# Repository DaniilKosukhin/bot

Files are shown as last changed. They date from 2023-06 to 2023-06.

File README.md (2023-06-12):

# bot

The bot passed three tests out of four in 2 minutes and 12 seconds

To meet the condition of the project were chosen not round wheels, but spiked in 4 rows of cones.

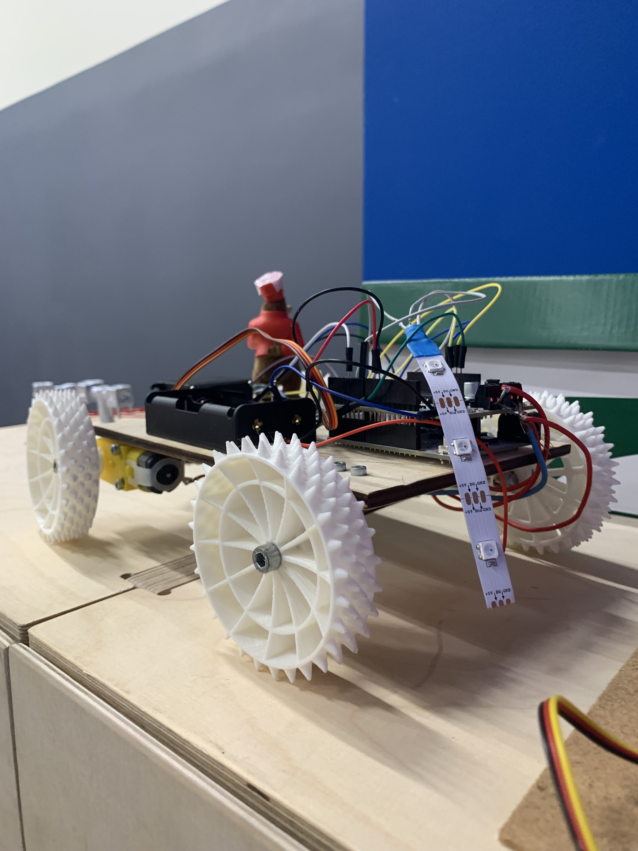
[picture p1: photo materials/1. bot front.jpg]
bot front


Bear holds radio module on his hat, for quality signal reception

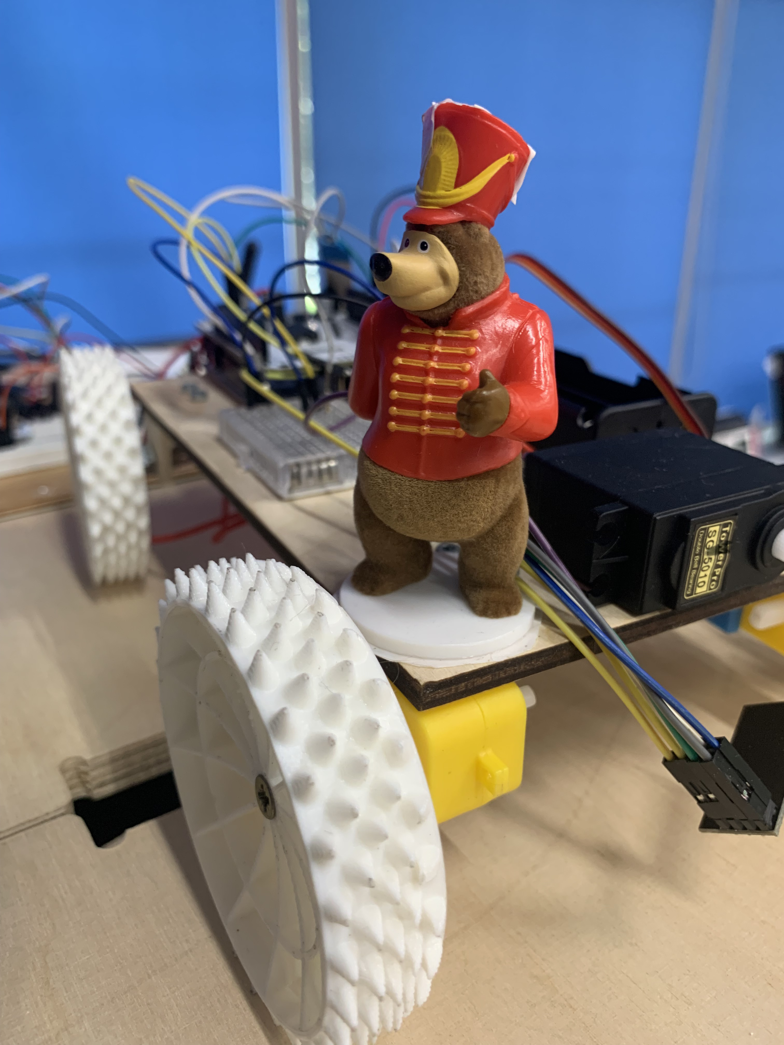
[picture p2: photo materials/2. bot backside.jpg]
bot backside


Joystick components assembled on a piece of cardboard

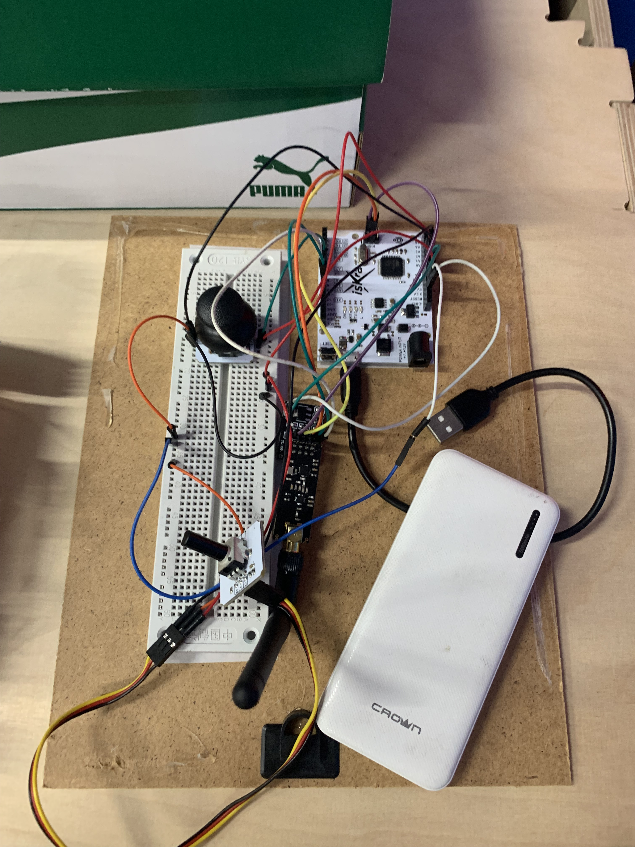
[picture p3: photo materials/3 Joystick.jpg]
joystick


Robot in motion :oncoming_automobile:

https://github.com/DaniilKosukhin/bot/assets/114745140/df838239-0182-4846-968c-9d25e73ed891

### componenets:
+ 3D jostick
+ amperka iskra NEO 2x
+ NRF
+ NRF +
+ 5v to 3.3 v
+ potentiometer
+ powerbank
+ servo 360
+ RGB LED matrix
+ battery holder
+ Motor Shield
+ DC motor 2x

### bot code:

```Python
#include <SPI.h>
#include <RF24.h>
#include <nRF24L01.h>
#include <Servo.h>
#include <Adafruit_NeoPixel.h>

#define SPEED_1      5 
#define DIR_1        4
 
#define SPEED_2      6
#define DIR_2        7

#define LED_COUNT 3
#define MATRIX_PIN 12

Adafruit_NeoPixel matrix = Adafruit_NeoPixel(LED_COUNT, MATRIX_PIN, NEO_GRB + NEO_KHZ800);

const uint64_t pipe = 0xF0F1F2F3F4LL;

RF24 radio(9, 10);

int data[5];

Servo rotServo; 
int servoAngle;

void setup(){
 Serial.begin(9600);
 radio.begin(); 
 radio.setChannel(3);
 radio.setDataRate(RF24_1MBPS);
 radio.setPALevel (RF24_PA_HIGH); 
 radio.openReadingPipe(1, pipe); 
 radio.startListening();
 
  for (int i = 4; i < 8; i++) {     
    pinMode(i, OUTPUT);
  } 

  rotServo.attach(2);
  matrix.begin();
} 

void loop() {

 if (radio.available()) {

    radio.read(&data, sizeof(data));

    int ptmrVal = data[0];
    int btnState = data[1];

    servoAngle = map(ptmrVal, 0, 1023, 0, 180); 
    rotServo.write(servoAngle); 
    Serial.println(ptmrVal);

      if (btnState == 0) {
        for (int i = 0; i < LED_COUNT; i++) {
          matrix.setPixelColor(i, matrix.Color(255,0,100));
        }
        matrix.show();
      }
      else {
        for (int i = 0; i < LED_COUNT; i++) {
          matrix.setPixelColor(i, matrix.Color(0,0,0));
        }
        matrix.show();
      }
      
    switch (data[2]) {
      case 0: {
        digitalWrite(DIR_1, HIGH); // set direction
        analogWrite(SPEED_1, data[3]); // set speed

        digitalWrite(DIR_2, HIGH); 
        analogWrite(SPEED_2, data[3]); 

        break;
      }
      case 1: {
            digitalWrite(DIR_1, LOW);
            analogWrite(SPEED_1, data[3]); 

            digitalWrite(DIR_2, LOW);
            analogWrite(SPEED_2, data[3]); 

            break;
          }
        case 2: {
          digitalWrite(DIR_1, LOW);
          analogWrite(SPEED_1, data[3]); 

          digitalWrite(DIR_2, HIGH);
          analogWrite(SPEED_2, data[3]); 

          break;
        }
        case 3: {
          digitalWrite(DIR_1, HIGH);
          analogWrite(SPEED_1, data[3]); 

          digitalWrite(DIR_2, LOW);
          analogWrite(SPEED_2, data[3]); 

          break;
        }
        case 4: {
          digitalWrite(DIR_1, LOW);
          analogWrite(SPEED_1, 0); 

          digitalWrite(DIR_2, LOW);
          analogWrite(SPEED_2, 0); 

          break;
        }
    }
  }
}
```

### jostick code:

```Python
#include <SPI.h>
#include <RF24.h>
#include <nRF24L01.h>

const uint64_t pipe = 0xF0F1F2F3F4LL;

RF24 radio(9, 10);

int data[5];

const int ptmrPin = A5;
const int buttonPin = 7;
const int xPin = A0;
const int yPin = A1;

int ptmrState = 0;
int buttonState = 0;
int xPosition = 0;
int yPosition = 0;

int speed = 0;
int direction = 0;

void setup(){
 Serial.begin(9600);

 radio.begin(); 
 radio.setChannel(3);
 radio.setDataRate(RF24_1MBPS);
 radio.setPALevel (RF24_PA_HIGH); 
 radio.openWritingPipe(pipe); 
 radio.stopListening(); 

 pinMode(ptmrPin, INPUT);
 pinMode(buttonPin, INPUT_PULLUP);
 pinMode(xPin, INPUT);
 pinMode(yPin, INPUT);
} 

void loop() {

 ptmrState = analogRead(ptmrPin);
 buttonState = digitalRead(buttonPin);
 xPosition = analogRead(xPin);
 yPosition = analogRead(yPin);

  if (yPosition < 400) {
        // go forward
        direction = 0; // 0 - Forward, 1 - backward, 2 - right, 3 - left
        speed = map(yPosition, 400, 10, 5, 255);
      }
      else if (yPosition > 600) {
        // go backward
        direction = 1;
        speed = map(yPosition, 600, 950, 5, 255);
      }
      else if (xPosition < 400) {
        // go right
        direction = 2; // 0 - Forward, 1 - backward, 2 - right, 3 - left
        speed = map(xPosition, 400, 0, 5, 255);
      }
      else if (xPosition > 600) {
      // go left
        direction = 3; // 0 - Forward, 1 - backward, 2 - right, 3 - left
        speed = map(xPosition, 600, 1000, 5, 255);
      }
      else if (yPosition < 600 || yPosition > 400  ) {
        // stop
        direction = 4;
        speed = 0;
      }

 data[0] = ptmrState;
 data[1] = !buttonState;
 data[2] = direction;
 data[3] = speed;

    radio.write(&data, sizeof(data));

    Serial.println(ptmrState); Serial.print(!buttonState);

    delay(100);
}
```

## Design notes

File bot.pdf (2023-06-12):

МИНИСТЕРСТВО НАУКИ И ВЫСШЕГО ОБРАЗОВАНИЯ РОССИЙСКОЙ

ФЕДЕРАЦИИ

ФЕДЕРАЛЬНОЕ ГОСУДАРСТВЕННОЕ АВТОНОМНОЕ

ОБРАЗОВАТЕЛЬНОЕ УЧРЕЖДЕНИЕ ВЫСШЕГО ОБРАЗОВАНИЯ

НАЦИОНАЛЬНЫЙ ИССЛЕДОВАТЕЛЬСКИЙ ТЕХНОЛОГИЧЕСКИЙ

УНИВЕРСИТЕТ «МИСиС»

ИНСТИТУТ Экотехнологий и инжиниринга

КАФЕДРА Металловедения цветных металлов

НАПРАВЛЕНИЕ 15.04.02 Технологические машины и оборудование

ПРАКТИКА ЦИФРОВОГО ПРОИВОДСТВА

на тему: «Робот на радиоуправлении»

Студент: Косухин Д.А.

Группа: МТМО-22-3

Преподаватель: Тавитов А.Г.

Москва, 2022

Введение

Целью практического занятия было создание робота на

радиоуправлении для прохождения полосы препятствий на время (Рис. 1).

Конструкция разрабатывалась исходя из сути испытаний и условия не

использовать колеса.

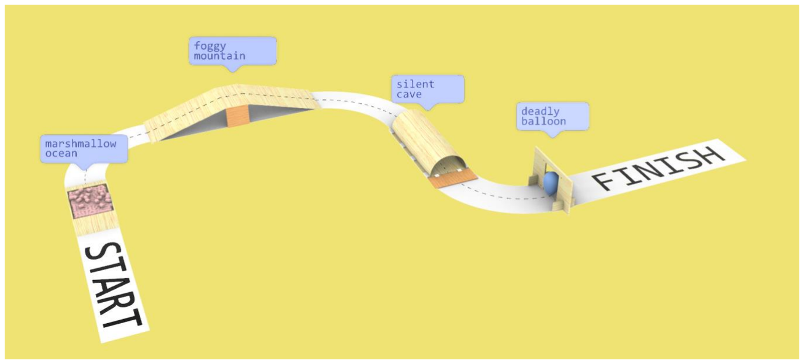
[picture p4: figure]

Рисунок 1 – Полоса препятствий. marshmallow ocean - бассейн с

зефиром глубиной 50 мм, foggy mountain - горка высотой 200 мм, шириной

320 мм и углом наклона 16 град., silent cave - тоннель длинной 1300 мм и

высотой 290 мм, ворота которого открываются при увеличениии

освещенности (срабатывает фоторезистор), deadly balloon - шарик,

привязанный к арке, отделяющий робота от финиша.

Компоненты

В проекте были использованы следующие компоненты:

1. 3D jostick
2. amperka iskra NEO 2x
3. NRF
4. NRF +
5. 5v to 3.3 v
6. potentiometer
7. powerbank
8. servo 360
9. RGB LED matrix
10. battery holder
11. Motor Shield
12. DC motor 2x

В последний день перед зачетом, техника отказывалась реагировать на

сигналы передатчика. Метод перебора каждого компонента, причина

поломки была найдена. Радиоприемный модуль, установленный на корпусе

машины, перестал принимать сигнал от передатчика на пульте.

В день экзамена радиомодуль удалось успешно заменить. Все

заработало.

Разработка изделия

В качестве основы корпуса робота был выбран лист МДФ, на лазерном

станке была получена заготовка толщиной 10 мм, шириной 200 мм и длиной

150 мм.

На сайте thingiverse.com была найдена модель колес, соответствующая

требованиям (рис. 2)

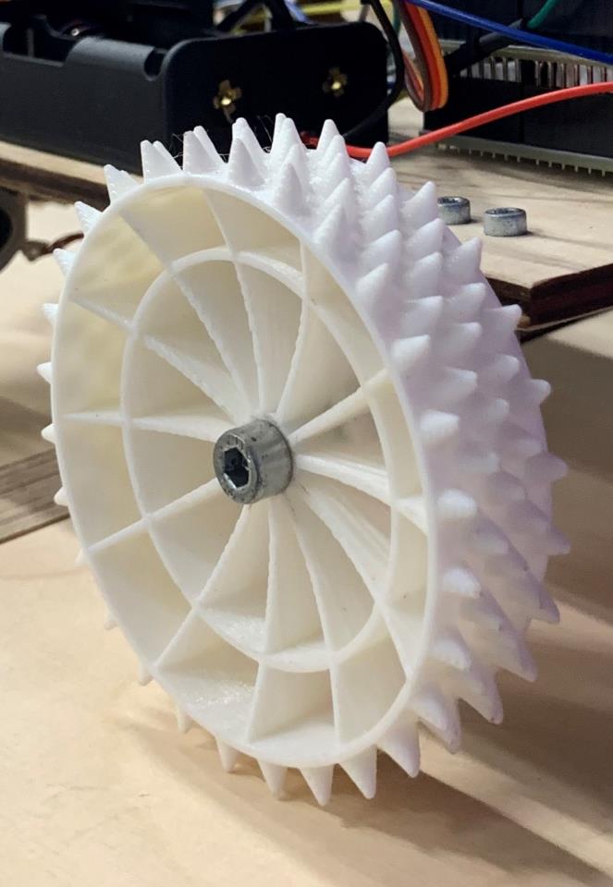
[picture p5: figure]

Рисунок 2 – Выбранная модель колес.

К МДФ были прикручены держатели моторов, предварительно

напечатанные на 3D принтере.

На следующем этапе возникла необходимость в разработке изделия,

способного соединить колеса и DC моторы. Деталь с одной стороны имеет многогранную выпуклую поверхность для сцепления с колесом, а с другой

отверстие для посадки с натягом с валом мотора.

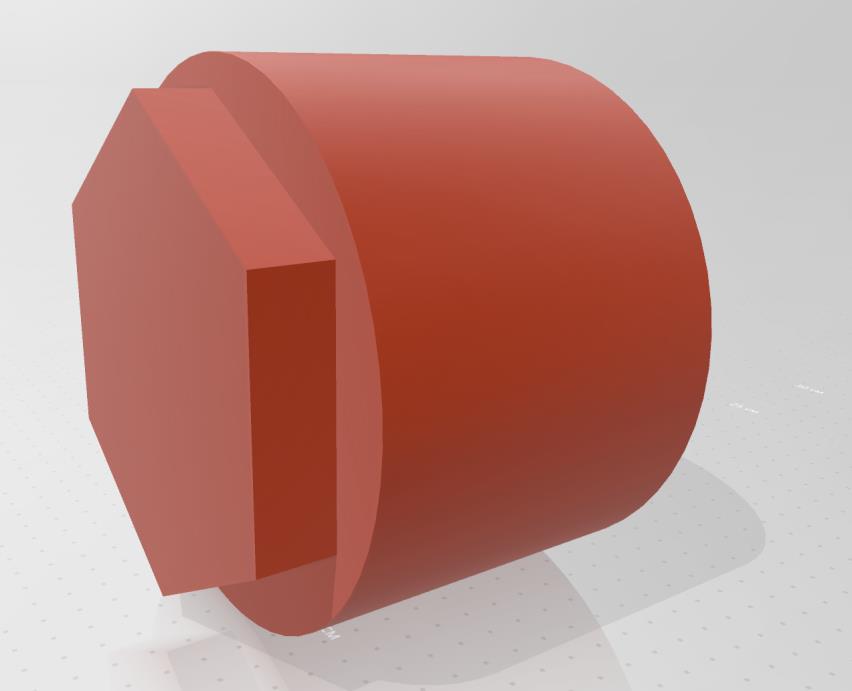
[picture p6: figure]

Рисунок 3 – Ступица колеса

Для переднего моста были распечатаны стандартные держатели,

приложенные к описанию проекта. Пришлось потратить немалое количество

времени, дабы грамотно подобрать длину винта и количество, а также

форму гаек.

Все детали были жестко зафиксированы на основании через болты М3

(в основном), а вот электронные компоненты преимущественно на

двухсторонний скотч за исключением приемного модуля, который

расположился на игрушечной модели медведя.

В качестве инструмента для прохождения последнего испытания

должно было использоваться классическое лезвие для бритья,

приводящееся во вращательное движение посредством сервопривода.

Однако, отказ техники не позволил осуществить этот замысел.

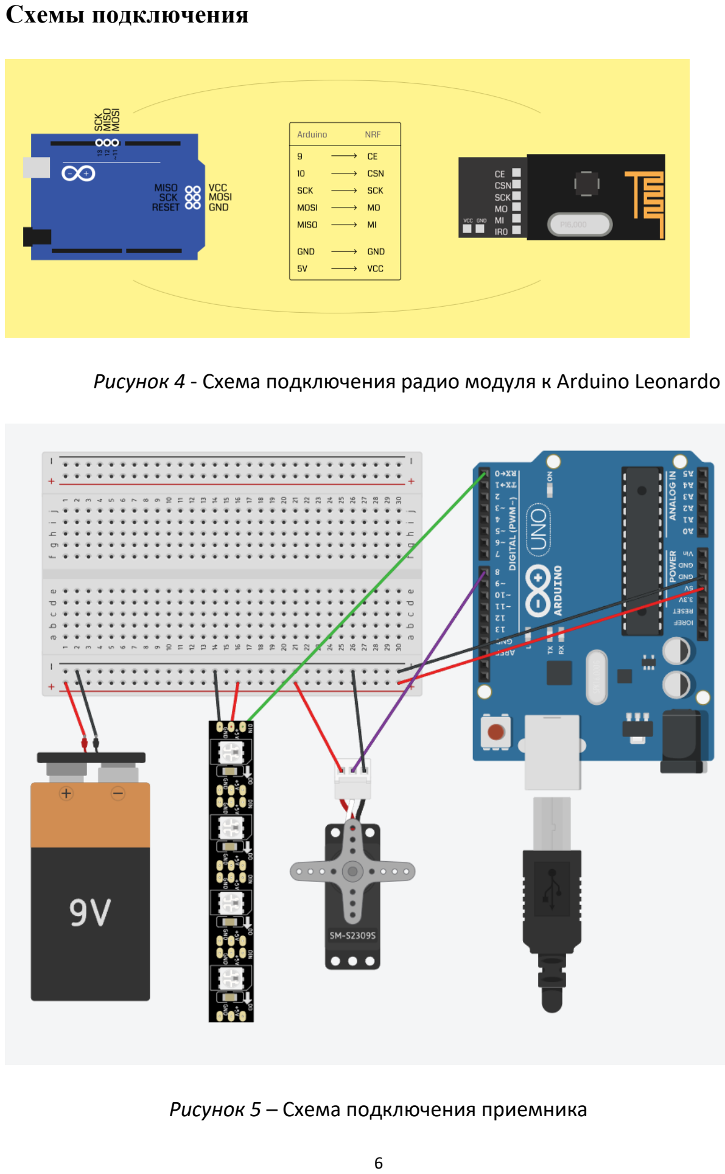
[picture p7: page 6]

Схемы подключения

Рисунок 4 - Схема подключения радио модуля к Arduino Leonardo

Рисунок 5 – Схема подключения приемника

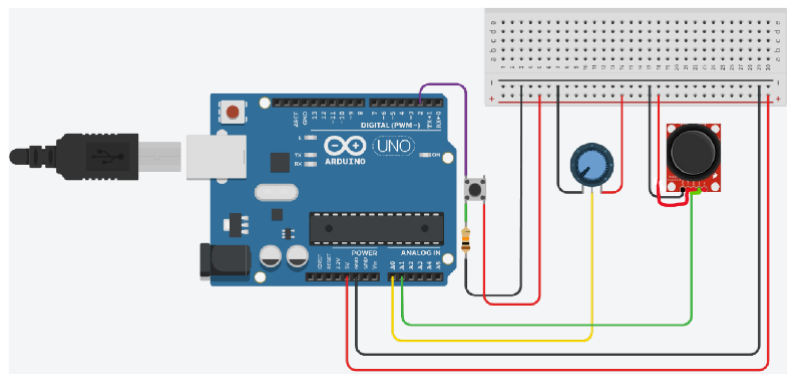
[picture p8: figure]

Рисунок 6 – Схема подключения передатчика

Заключение

В ходе выполнения работы был получен драгоценный опыт и навыки

работы с печатью на 3D принтере, резкой древовидных материалов на

лазерном станке, сбор схем и программирование плат и компонентов. Полоса

испытаний и конкуренция с коллегами придали этому конкурсу дух азарта и

подарили незабываемые эмоции.

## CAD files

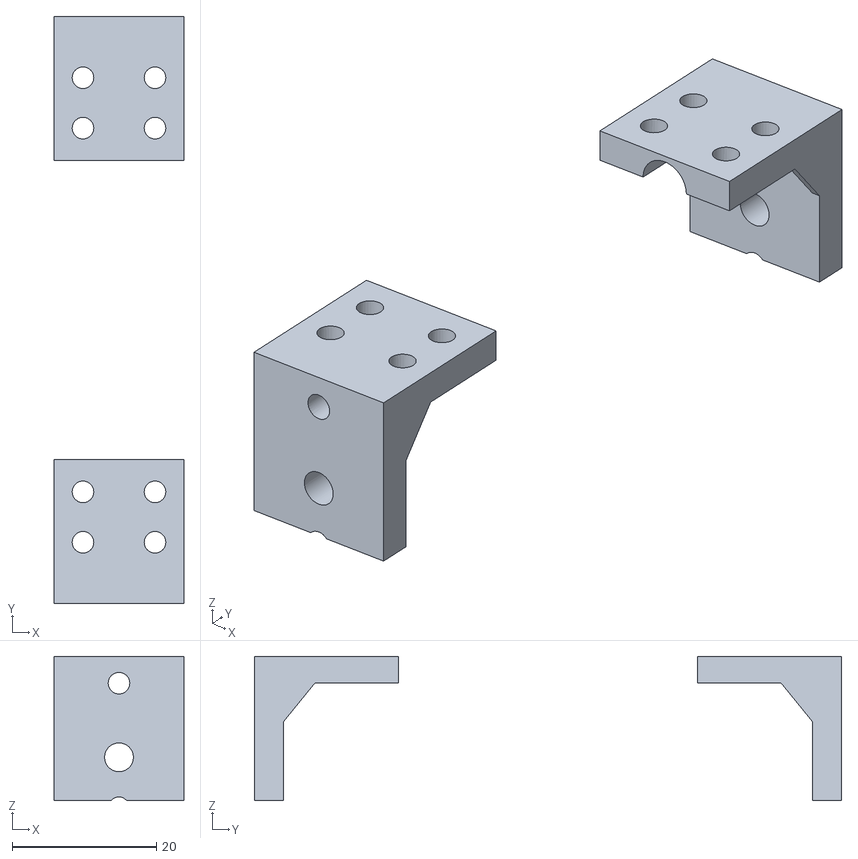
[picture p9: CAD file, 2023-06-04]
STL/Leg_holder.stl
18.0 x 81.5 x 20.0

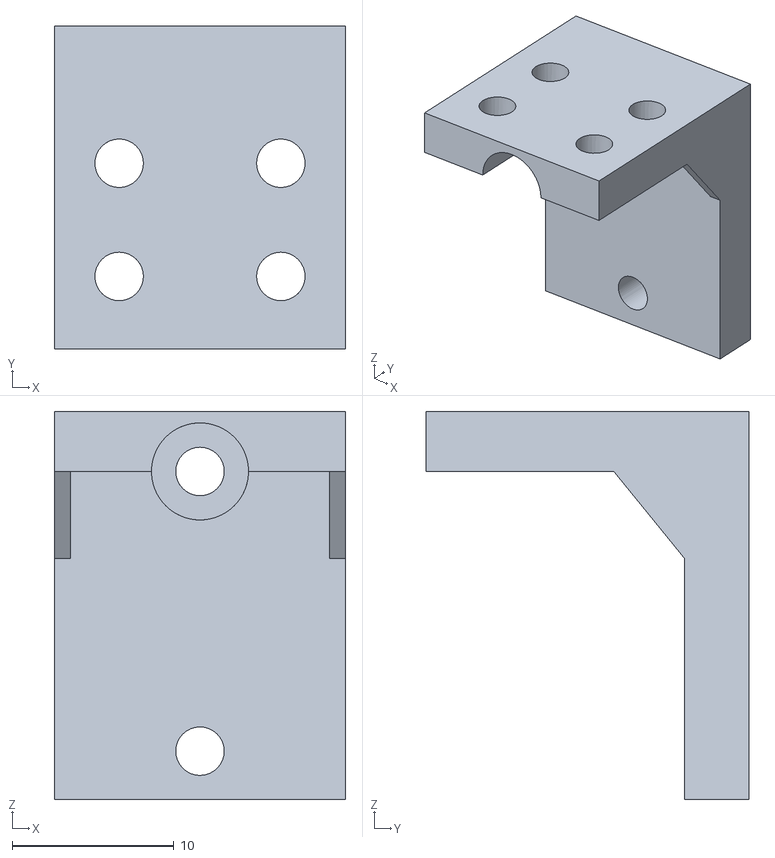
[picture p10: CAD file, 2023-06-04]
STL/Mototr_holder.stl
18.0 x 20.0 x 24.0

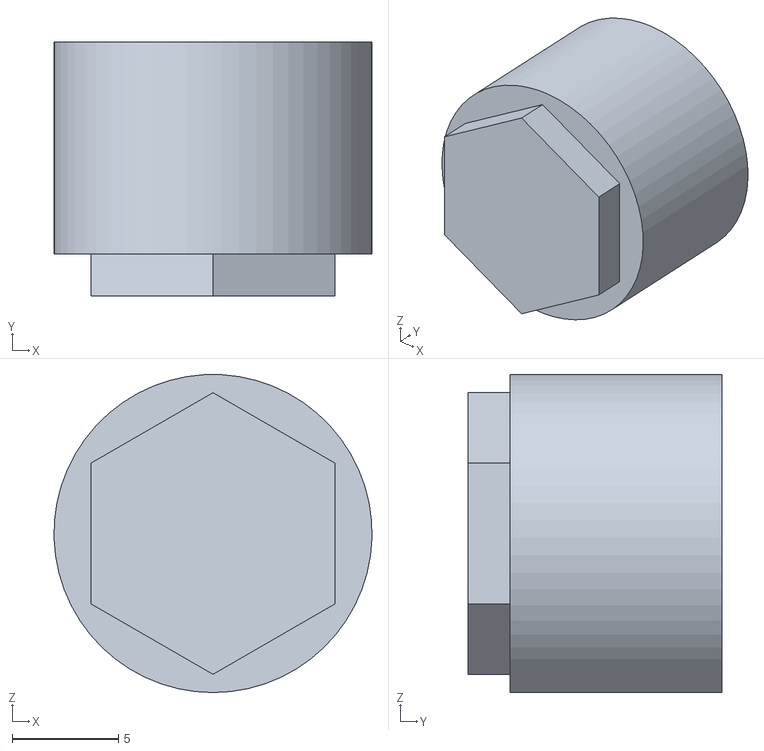
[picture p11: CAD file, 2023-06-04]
STL/Wheel hub.STL
15.0 x 12.0 x 15.0

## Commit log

2023-06-02 photo material
2023-06-02 Create photo materials
